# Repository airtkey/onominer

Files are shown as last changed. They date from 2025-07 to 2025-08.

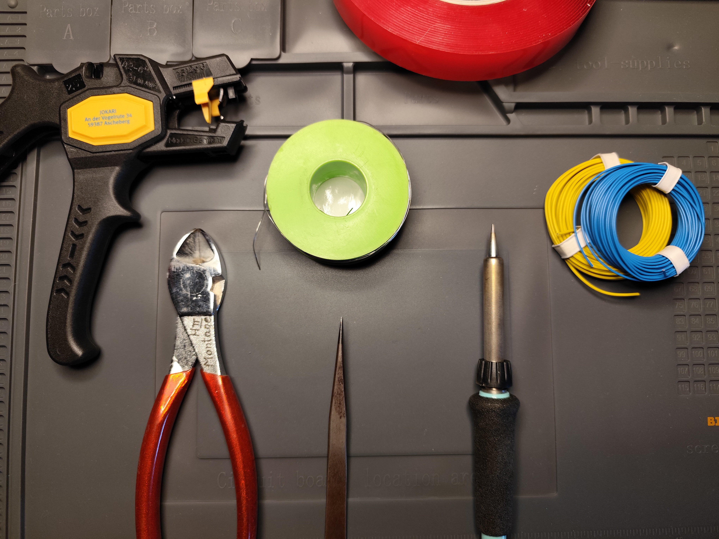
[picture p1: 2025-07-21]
pictures/IMG_20250701_153013.jpg

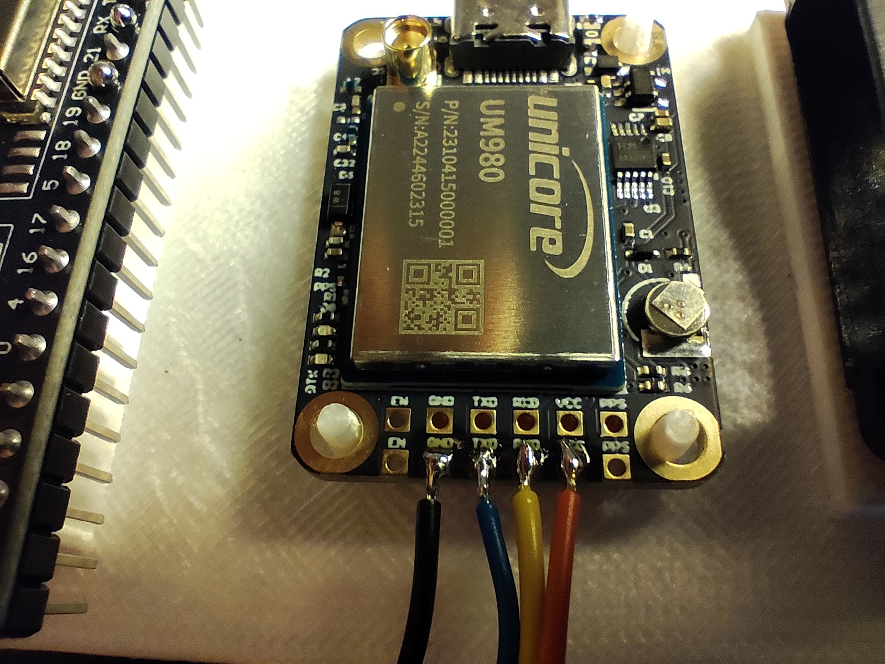
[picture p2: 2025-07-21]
pictures/IMG_20250701_170632.jpg

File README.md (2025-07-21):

DIY Guide: onocoy Miner with ESP32 and UM980 GPS Module 

Deployment Requirements 
Power supply: USB-C adapter and cable, permanently connected 
Internet connection: online 24/7 
Antenna placement: Unobstructed 360° view of the sky 
Mounting: Stable and vibration-free antenna installation
 
Requirements: Basic soldering skills – the GPS module is sensitive! 

Required Hardware:
ESP32 WROOM (with external WiFi antenna) 
UM980 GPS module 
4010 fan 
USB-C socket 

Required Tools & Materials 
ESD-safe soldering station (fine tip) 
Side cutters 
Wire stripper 
Wire in 4 colors (e.g. black, red, yellow, blue) 
Double-sided 3M tape 
M3 thread cutter (optional, if the lid is to be screwed), 2 x M3 screws and screwdriver 

.. Step 1: Prepare Firmware 
Before connecting the components, flash the ESP32 with the correct firmware. 
You will need: 
- Firmware file: ESP32 NTRIP duo.bin ( THANKS to: https://github.com/incarvr6/esp32-ntrip-DUO )
 
Using ESPHome Web Flasher: 
1. Open: https://web.esphome.io/ 
2. Connect the ESP32 to your PC via USB (hold the 'Boot' button while plugging in) 
3. Click 'Connect' and choose the COM port (if no COM port appears, install a driver. A pop-up will provide links. Alternatively, go to the 'ESP32' folder, unpack the driver archive, and right-click on silabser.inf . 'Install'.) 
4. In the popup: Select the .bin file 
5. Click 'Install' 
 
After flashing: Disconnect and reconnect the USB cable. After about 20 seconds, a new WiFi network named 'ESP32-...' should appear. 
.. Step 2: Configure the UM980 GPS Module 
1. Install the driver from the 'GPS MODULE / Driver' folder 
2. Connect the UM980 to your Windows PC via USB 
3. Copy the 'GPS MODULE' folder to your desktop 
4. Open Device Manager . Note the COM port (CH340) 
5. Open terminal in the folder (Right-click . 'Open in Terminal') 
6. Run the flashing command: 
 
.\nmeaConf.exe COM5 UM980_RTCM3_OUT.txt 
 
(Replace COM5 with your actual COM port, e.g., COM3, COM4, etc.) 
Done! 

... Step 3: Prepare the Enclosure (optional, if lid is not screwed) 
Carefully cut threads into both enclosure holes using the M3 thread cutter. 

... Step 4: Assembly & Wiring 
1. Attach double-sided tape to ESP32, fan, and UM980 
2. Cut 4 wires (each in a different color) to 6 cm, strip both ends, twist, and lightly tin them 
3. Wiring according to the following diagram: 
4010 Fan: 
ESP32 3V  . Fan + (red) 
ESP32 GND . Fan – (black) 
UM980 GPS Module: 
ESP32 TX  . UM980 RX (yellow) 
ESP32 RX  . UM980 TX (blue) 
ESP32 5V  . UM980 VCC (red) 
ESP32 GND . UM980 GND (black) 
. Step 5: Power-up 
1. Close the enclosure 
2. Connect the antennas 
3. Plug in power . The device will start automatically 
4. Now you can begin with the software setup. Follow the instructions at device setup.pdf.

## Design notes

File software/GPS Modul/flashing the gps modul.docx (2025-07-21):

## Flashing the GPS Module UM980 for onocoy miner

- Connect your um980 with usb cable to your windows pc
- Copy the folder GPS MODUL on your pc
- Have a look in the device-manager, which com port have the um980 (if you don’t see the modul as usb serial ch340, you have to install the driver ( I put it in the esp32 folder)

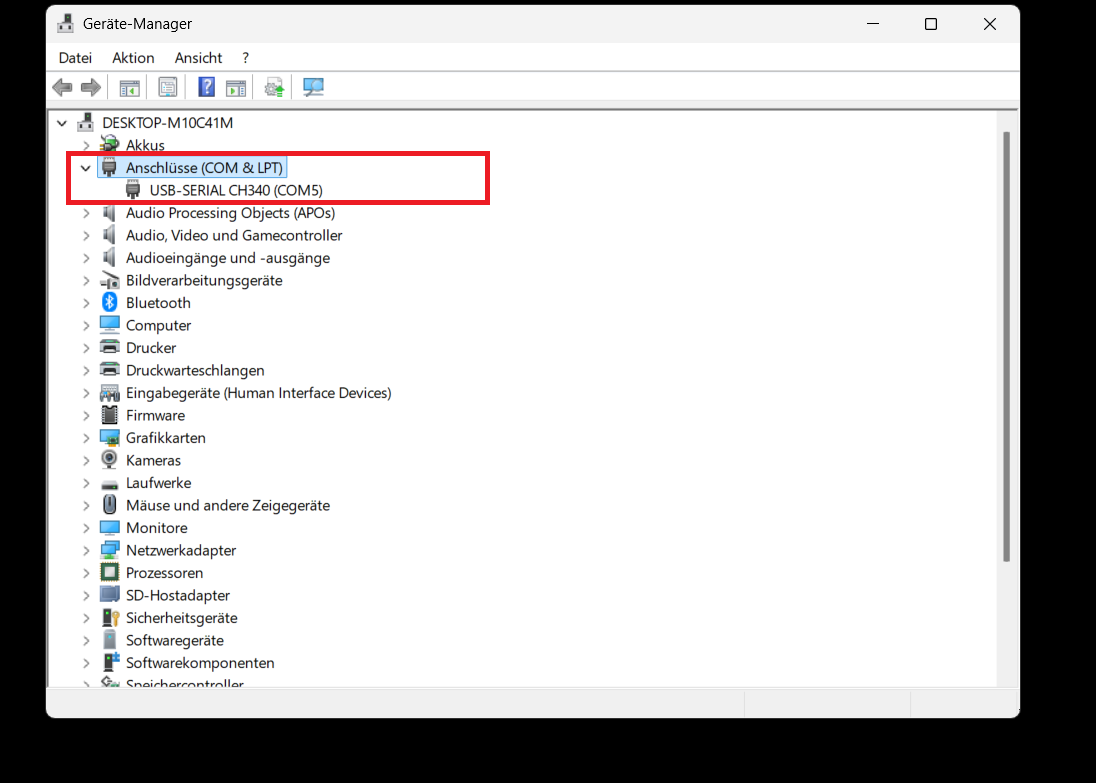
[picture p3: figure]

- Open a terminal, easiest way is right click the gps module folder and “open terminal” (on the picture as “Im Terminal öffnen”

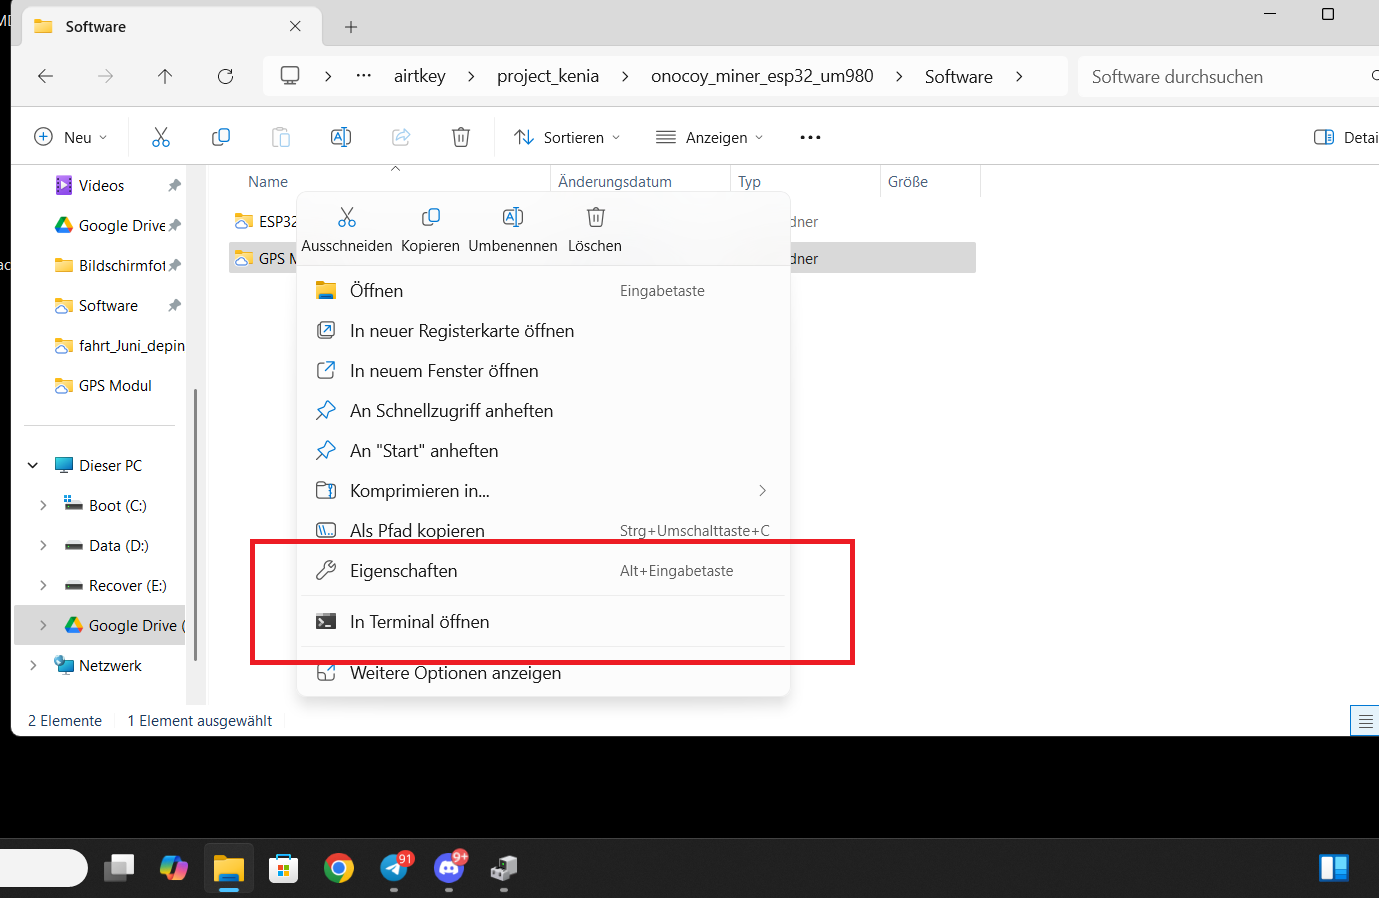
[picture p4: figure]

- Start flashing with: (if you have com port 4, chance COM5 to COM4)

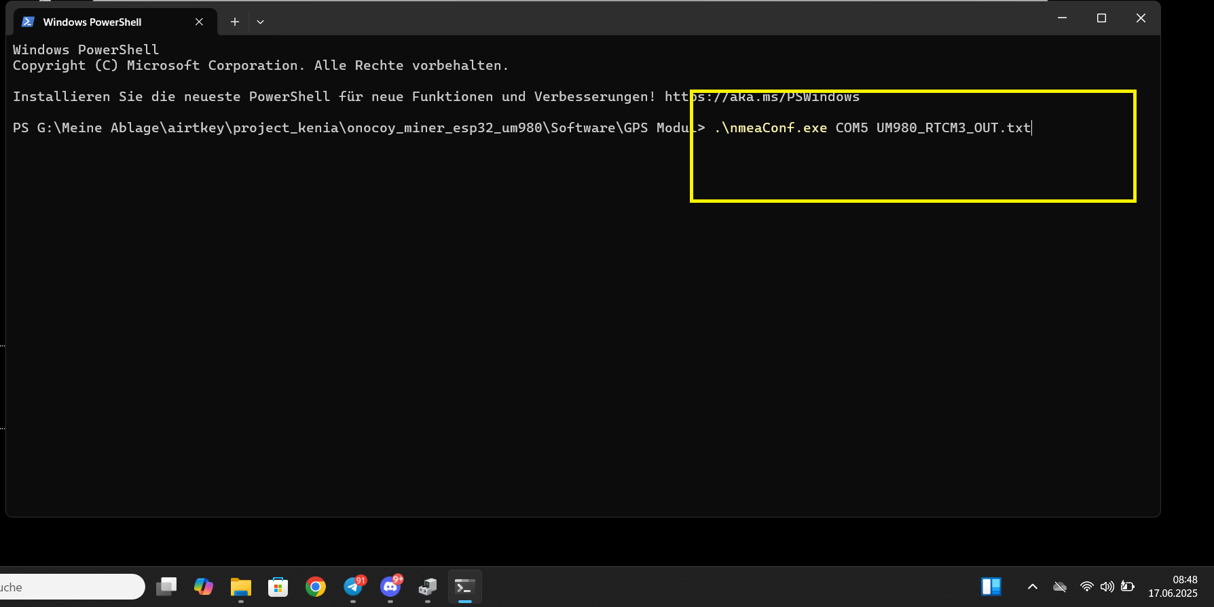
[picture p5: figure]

- flashing is done and ok:

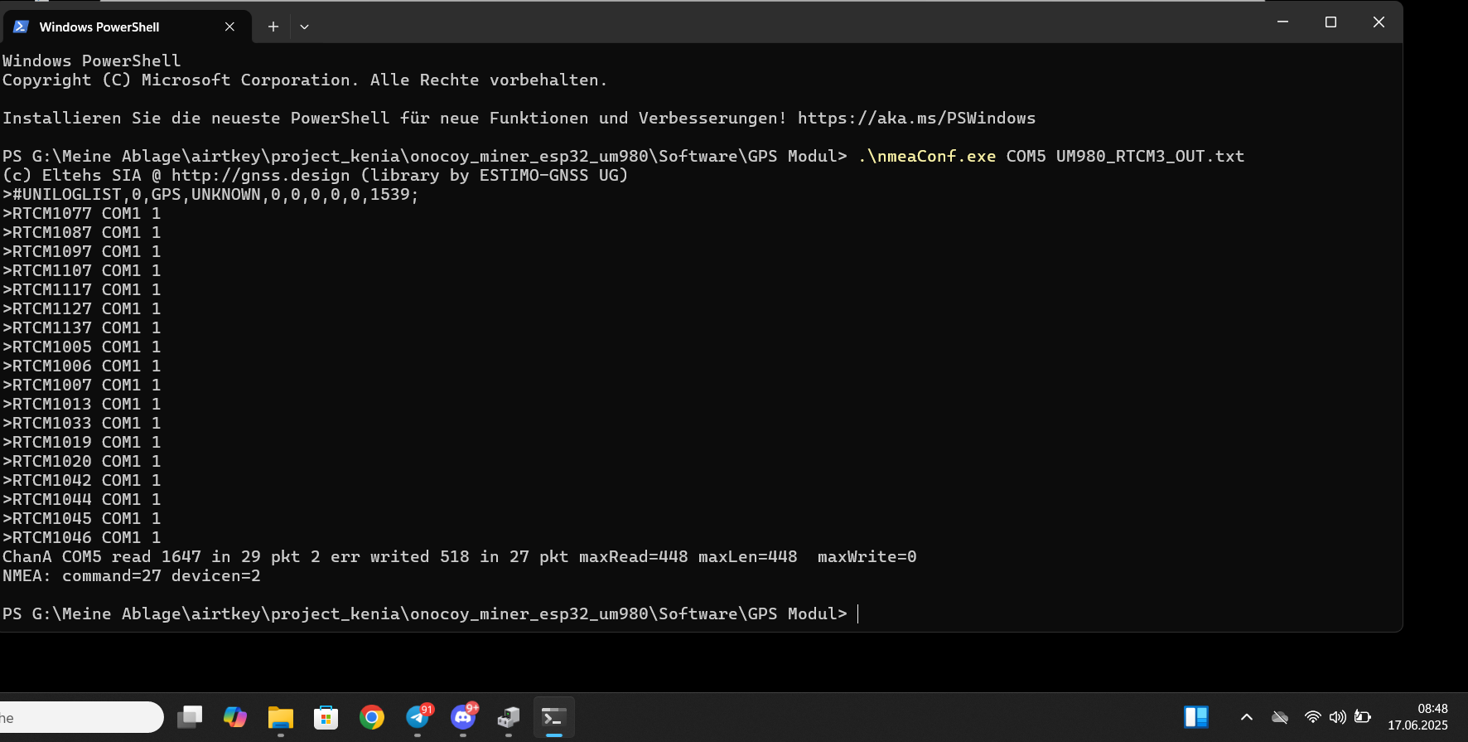
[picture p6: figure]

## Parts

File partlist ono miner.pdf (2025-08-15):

# ONO Miner

Item Name | Description | Quantity | Unit Price (€) | Supplier | Order No. / Link | Notes
Microcontroller | ESP32-WROOM-32U Set incl. Antenna | 1 ~ 7 € | Aliexpress | https://de.aliexpress.com/item/1005008209944531.ht ml
GNSS Module | UM980 | 1 ~ 115 € | Aliexpress | https://aliexpress.com/item/1005007176550873.html its incl. Alu heatsink, antenna cable
Fan | 3010 | 1 ~ 5 € | Aliexpress | https://aliexpress.com/item/4000313538245.html
| | | | | | A fan is not strictly necessary, but it is recommended when used in hot environments such as under a roof or in outdoor enclosures.

USB C Cable and Power
Adapter

For Splitting with Geodnet:

Splitter | QY-PS2 2-Way | 1 ~ 25 € | Aliexpress | https://aliexpress.com/item/1005006176035221.html
Cable from Splitter to Miner | SMA M to SMA M | 2 ~ 3 € | Aliexpress | https://aliexpress.com/item/1005001287923172.html

For standalone use:

Antenna + cable | EM-500 Antenna + cable SMA end | 1 ~ 82€ | Aliexpress | https://aliexpress.com/item/1005008631266282.html Make sure it has the correct connector type: SMA
Pole | Pole | 1 ~ 9 € | Aliexpress | https://aliexpress.com/item/1005006425749599.html

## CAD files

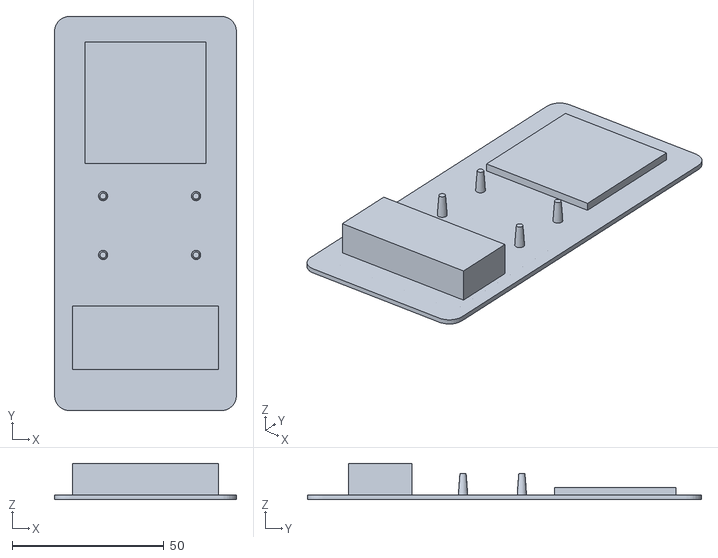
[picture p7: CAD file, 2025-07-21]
case_3d_print/assembly aid.stl
60.0 x 130.0 x 12.0

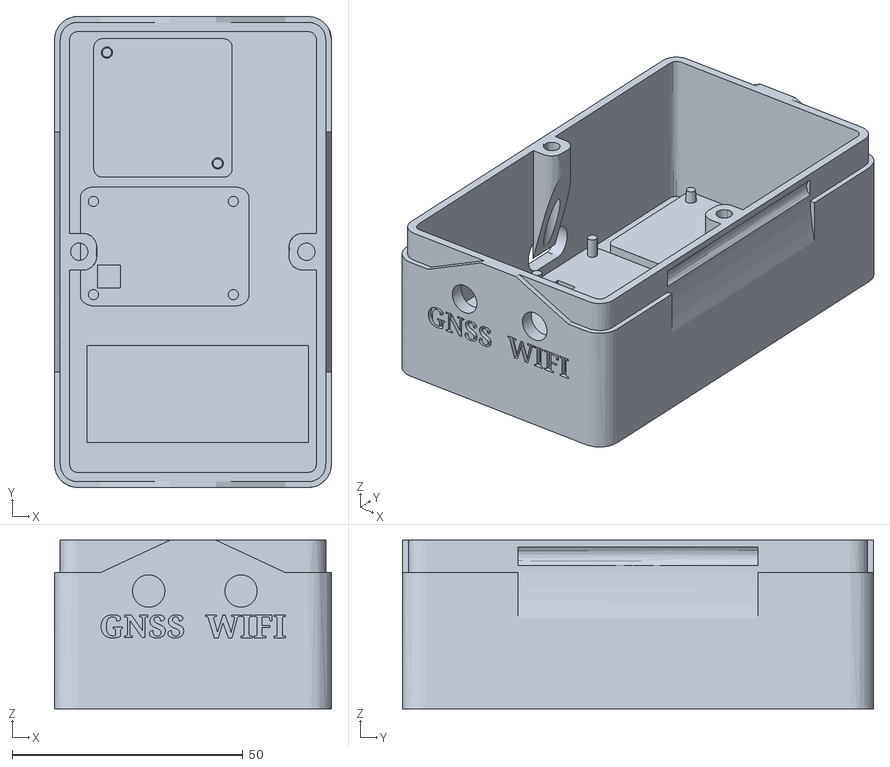
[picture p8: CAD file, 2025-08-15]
case_3d_print/case V2/case v2.stl
60.0 x 102.0 x 36.5

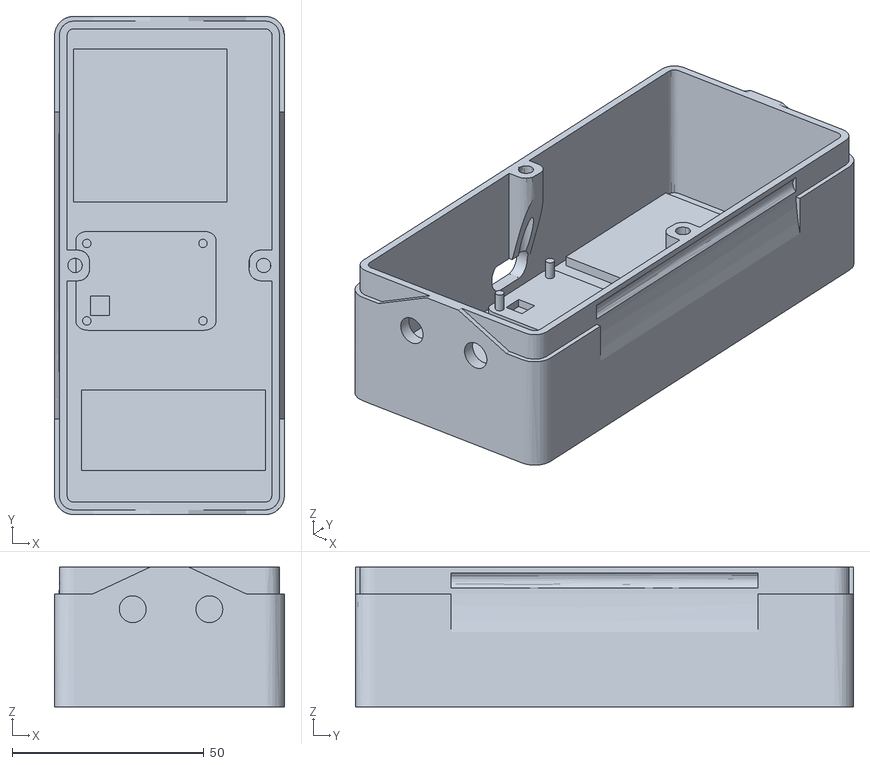
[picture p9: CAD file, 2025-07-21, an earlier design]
case_3d_print/case/case without extra usb plug.stl
60.0 x 130.0 x 36.5

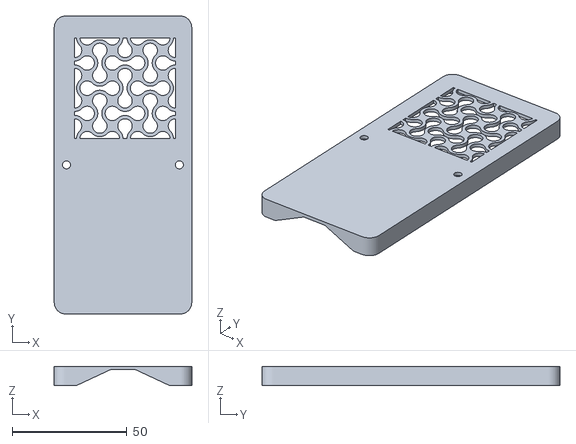
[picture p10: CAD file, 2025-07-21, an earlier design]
case_3d_print/case/lid/lid_open.stl
60.0 x 130.0 x 8.50

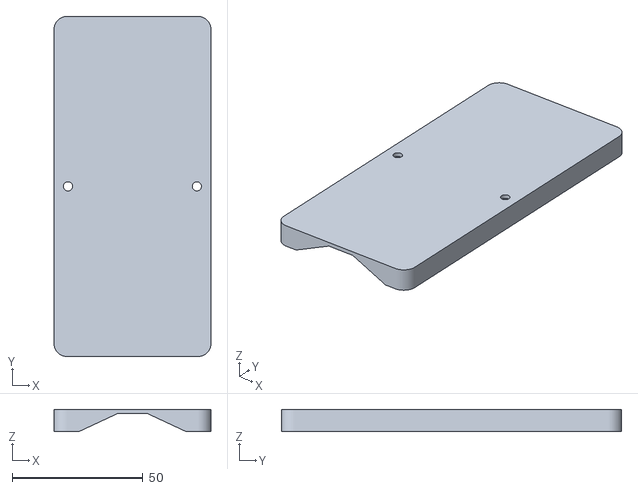
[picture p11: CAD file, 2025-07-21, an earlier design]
case_3d_print/case/lid/lid_closed.stl
60.0 x 130.0 x 8.50

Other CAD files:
case_3d_print/case V2/lid v2 onocoy version.stl

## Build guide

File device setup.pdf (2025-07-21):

## Setting up the device

Make sure that the GNSS antenna is mounted with a good 360° view to the sky and in such a way that it will not move while active. Plug-in the USB-C power supply to start operation.

Under no circumstances should the GNSS antenna be re-positioned while the device is powered. If you need to change the antenna location, unplug the device power, change the antenna position and then, with the antenna tightly fixed, power on the device again.

Wi-Fi Connection and Internet Setup

Connect to the Device’s Wi-Fi:

1. Find and connect to the ESP32_XXXXXX (where XXXXXX is a unique number) device’s Wi-Fi network on your phone, PC, or Mac. Open a browser and navigate to http://192.168.4.1. (not https://) where you should be greeted by the configuration page:

Enable the WiFi module by clicking on the switch marked “1” in the screenshoot above. This will un-blur the WiFi configuration under “2”.

Enter your Wi-Fi SSID and password to connect the device to your home network and then press “send” button marked “3”.

The device will reboot, and the status LED will eventually indicate the Wi-Fi connection (blue double blink).

Register/login on console.onocoy.com/explorer

If we don’t already have an account created select the “Sign Up” button and follow these steps:

Step 1. Fill in the First Name, Last Name and e-mail address fields

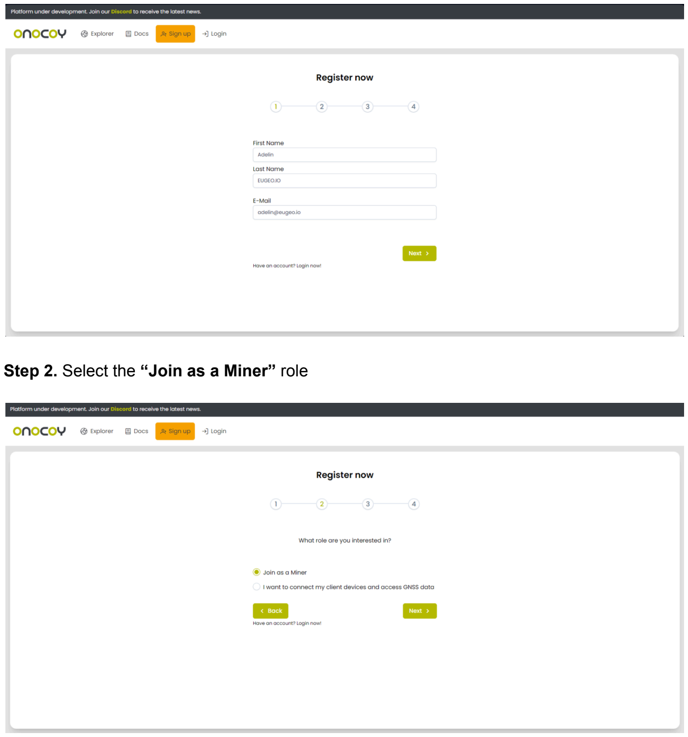
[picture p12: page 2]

Step 2. Select the “Join as a Miner” role

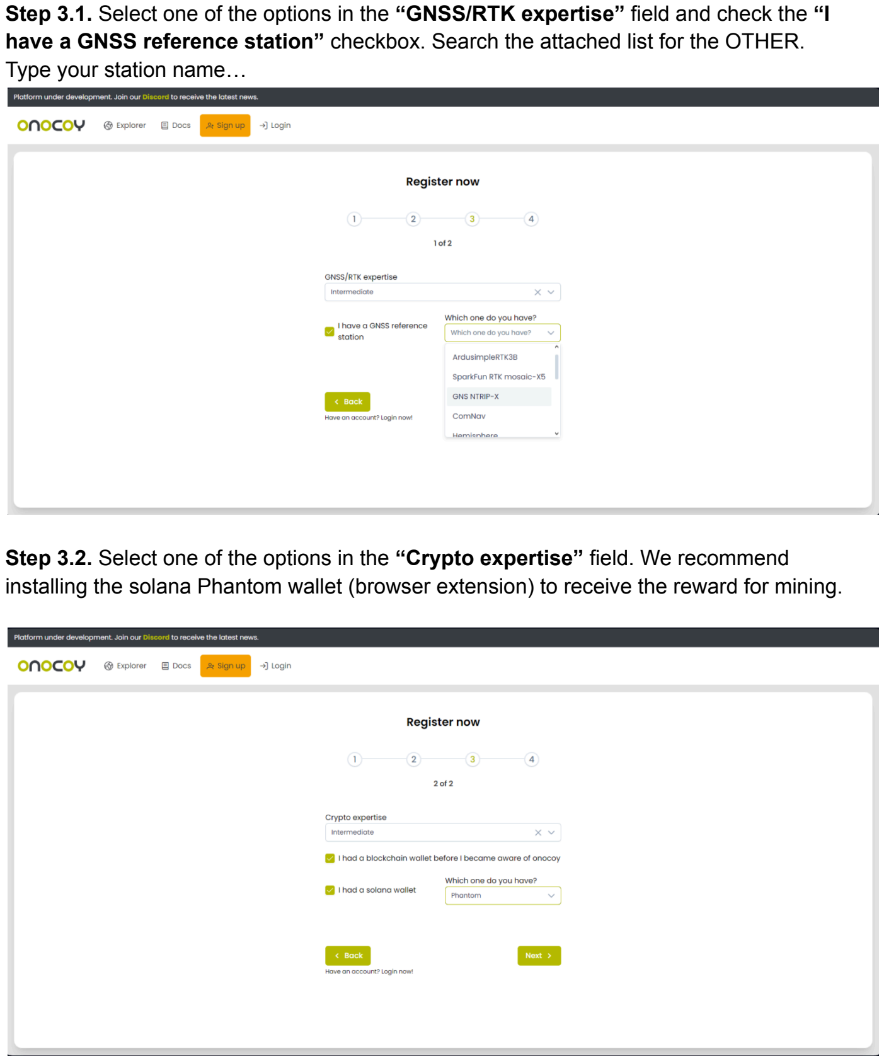
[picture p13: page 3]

Step 3.1. Select one of the options in the “GNSS/RTK expertise” field and check the “I have a GNSS reference station” checkbox. Search the attached list for the OTHER. Type your station name…
Step 3.2. Select one of the options in the “Crypto expertise” field. We recommend installing the solana Phantom wallet (browser extension) to receive the reward for mining.

Step 4 Answer the 2 questions and check the box (mandatory) “I accept the privacy policy”. Then click the “Register now” button

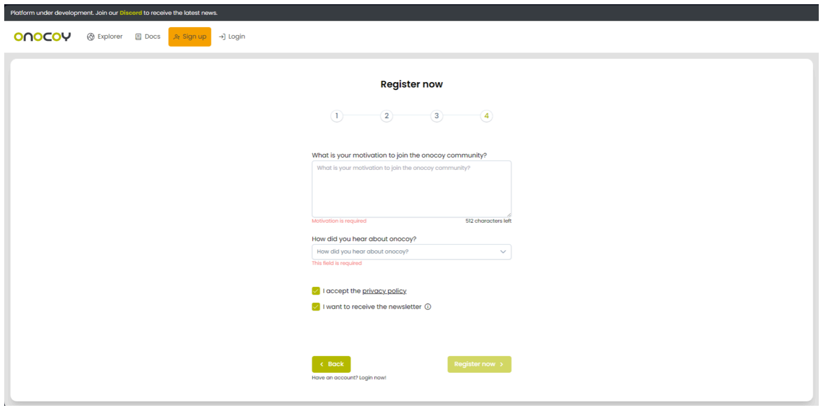
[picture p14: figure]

After completing these steps we just need to confirm our e-mail address.

If you already have an account created, ignore these steps and log in directly.

Adding the device in onocoy explorer

Go to the “Reference Stations” button, then “NTRIP Credentials” to add a new miner. Up to 3 miners can be added per new account. If you want to add to many it is necessary to send e-mail to info@onocoy.com

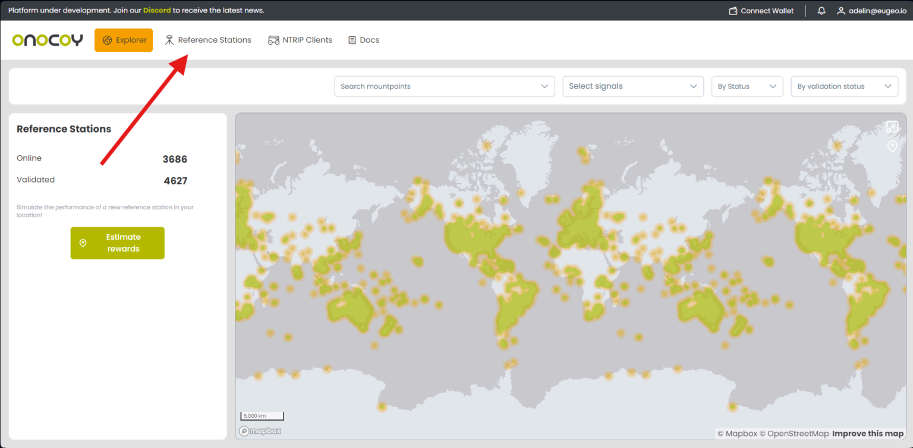
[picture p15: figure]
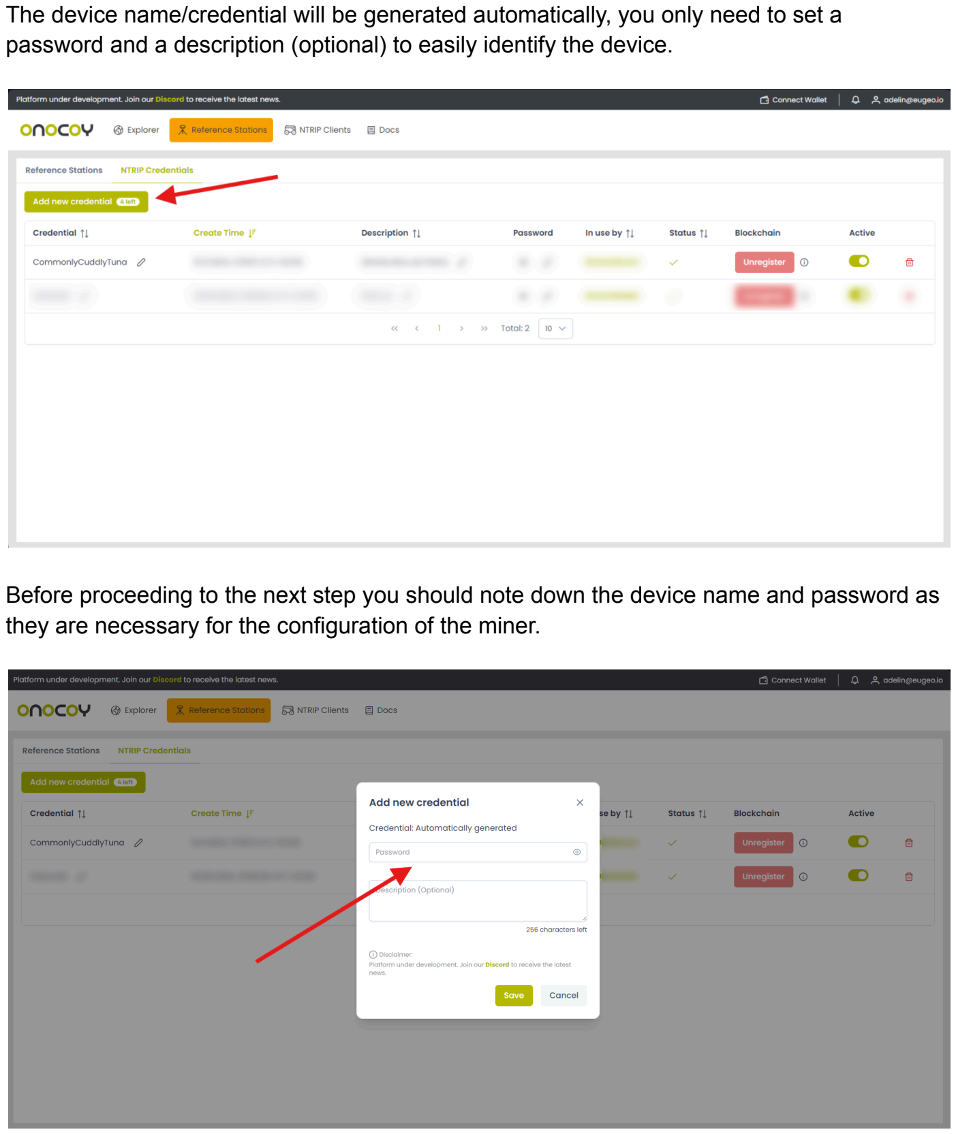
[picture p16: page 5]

The device name/credential will be generated automatically, you only need to set a password and a description (optional) to easily identify the device.

Before proceeding to the next step you should note down the device name and password as they are necessary for the configuration of the miner.

Configuring the NTRIP Client – Onocoy

After connecting the Wi-Fi network and securing the device, the NTRIP client needs to be configured to connect to an NTRIP server of your choice.
Enable the NTRIP client module by clicking on the switch in the upper right corner of the NTRIP client pane which will unblur the configuration area:

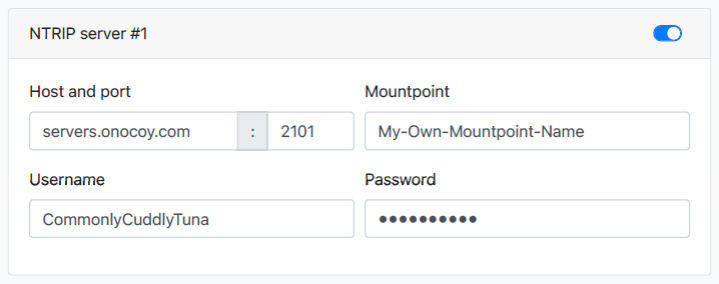
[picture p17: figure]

Enter the host name or IP address of the NTRIP server of your choice and change the port number if necessary, the standard port 2101 is pre-selected.
For onocoy: servers.onocoy.com

Enter the Mountpoint, Username and Password as supplied by the NTRIP server administrator and click the ‘Submit’ Button to activate the changes.

Mountpoint and Username are your credential name!
Dont use your account name as username

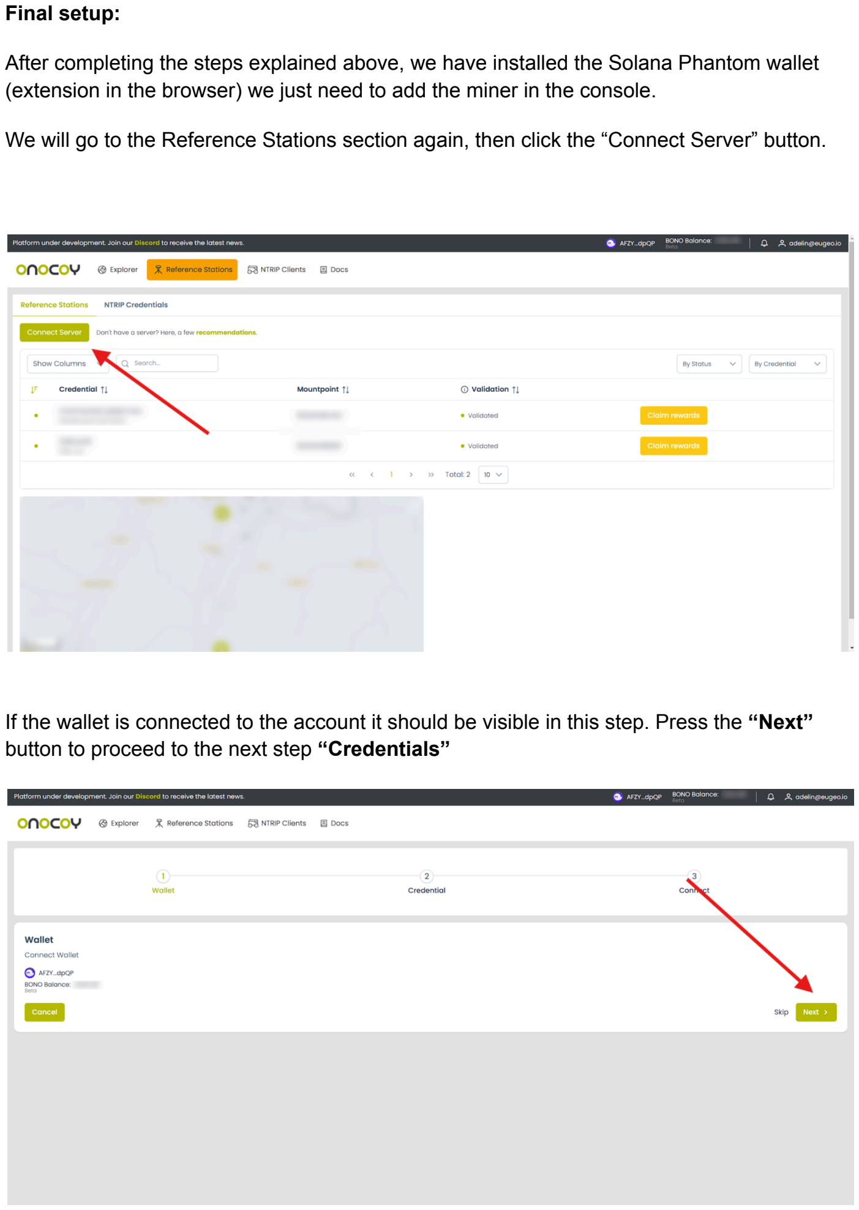
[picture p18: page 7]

Final setup:

After completing the steps explained above, we have installed the Solana Phantom wallet (extension in the browser) we just need to add the miner in the console.

We will go to the Reference Stations section again, then click the “Connect Server” button.

If the wallet is connected to the account it should be visible in this step. Press the “Next” button to proceed to the next step “Credentials”

In the following we will select our device from the list and press the “Next” button.

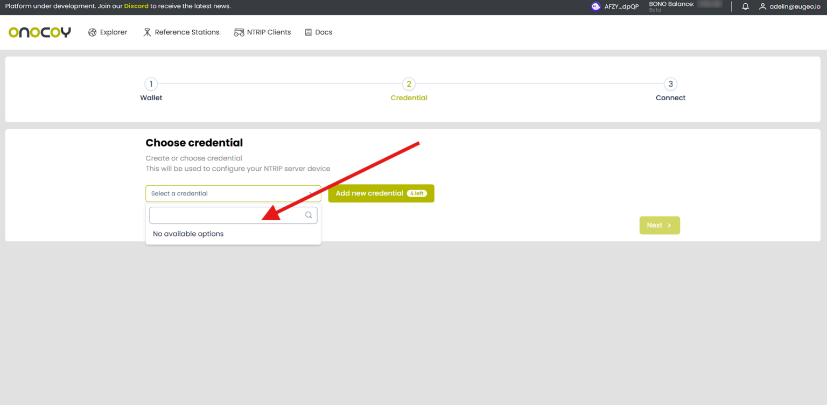
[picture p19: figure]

Finally, the last step (3) is where our device is displayed, connects to the blockchain and starts mining.
